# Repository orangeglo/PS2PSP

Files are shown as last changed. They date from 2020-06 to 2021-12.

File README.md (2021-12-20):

# PS2PSP

These are PCB design and arduino software files for a circuit board that converts a PS2 controller into signals a PSP2000 motherboard can understand. The circuit board is designed to have the PSP power cable routed through it, so you can boot up the PSP and the adapter with a basic toggle switch.

[Order from OSH Park](https://oshpark.com/shared_projects/nhHJAzdG)

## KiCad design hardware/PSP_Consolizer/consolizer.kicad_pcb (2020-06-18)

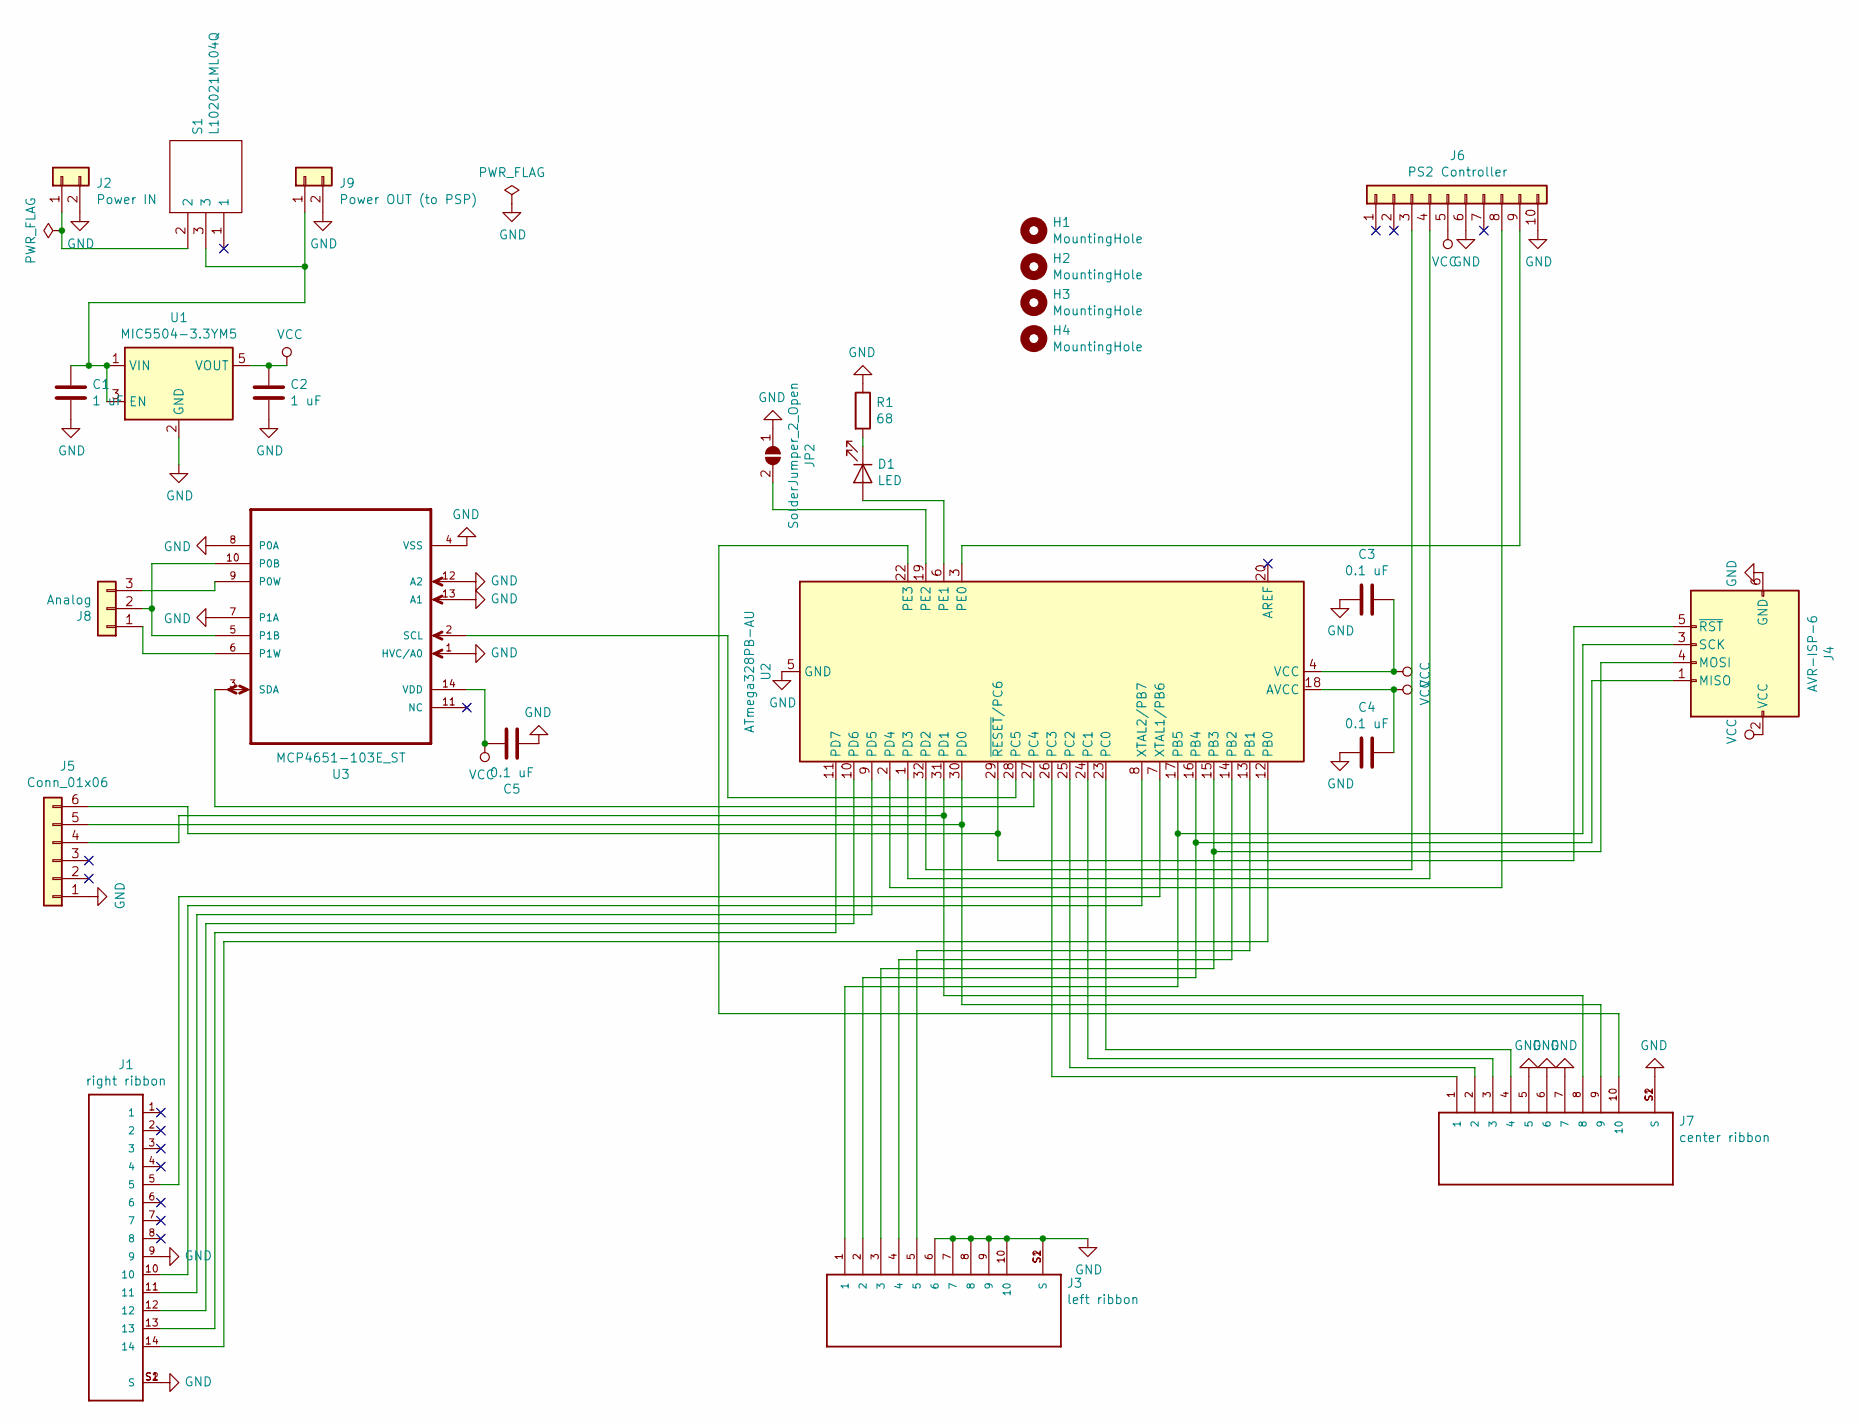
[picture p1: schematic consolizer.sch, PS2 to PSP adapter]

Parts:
C1, C2: 1 uF; C_0603_1608Metric_Pad1.05x0.95mm_HandSolder
C3, C4, C5: 0.1 uF; C_0603_1608Metric_Pad1.05x0.95mm_HandSolder
D1: LED; LED_0603_1608Metric_Pad1.05x0.95mm_HandSolder
H1, H2, H3, H4: MountingHole; MountingHole_2.2mm_M2
J1: right ribbon; TE_1-1734592-4
J2: Power IN; PinHeader_1x02_P2.54mm_Vertical
J3: left ribbon; TE_1-1734592-0
J4: AVR-ISP-6; PinHeader_2x03_P2.54mm_Vertical
J5: Conn_01x06; PinHeader_1x06_P2.54mm_Horizontal
J6: PS2 Controller; ps2_connector
J7: center ribbon; TE_1-1734592-0
J8: Analog; PinHeader_1x03_P2.54mm_Vertical
J9: Power OUT (to PSP); PinHeader_1x02_P2.54mm_Horizontal
JP2: SolderJumper_2_Open; SolderJumper-2_P1.3mm_Open_RoundedPad1.0x1.5mm
R1: 68; R_0603_1608Metric_Pad1.05x0.95mm_HandSolder
S1: L102021ML04Q; L102011ML04Q; Manufacturer_Part_Number L102021ML04Q; Mouser Part Number 611-L102021ML04Q
U1: MIC5504-3.3YM5; SOT-23-5
U2: ATmega328PB-AU; TQFP-32_7x7mm_P0.8mm
U3: MCP4651-103E_ST; SOP65P640X120-14N

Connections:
GND: C1.2, C2.2, C3.1, C4.1, C5.2, J1.9, J1.S1 (S), J1.S2 (S), J2.2, J3.6, J3.7, J3.8, J3.9, J3.10, J3.S1 (S), J3.S2 (S), J4.6 (GND), J5.1, J6.6, J6.10, J7.5, J7.6, J7.7, J7.S1 (S), J7.S2 (S), J9.2, JP2.1 (A), R1.1, U1.2 (GND), U2.5 (GND), U2.21 (GND), U3.1 (HVC/A0), U3.4 (VSS), U3.7 (P1A), U3.8 (P0A), U3.12 (A2), U3.13 (A1)
unnamed: C1.1, J9.1, S1.3, U1.1 (VIN), U1.3 (EN)
unnamed: D1.1 (K), R1.2
unnamed: D1.2 (A), U2.6 (PE1)
unnamed: J1.5, U2.7 (XTAL1/PB6)
unnamed: J1.10, U2.8 (XTAL2/PB7)
unnamed: J1.11, U2.9 (PD5)
unnamed: J1.12, U2.10 (PD6)
unnamed: J1.13, U2.11 (PD7)
unnamed: J1.14, U2.12 (PB0)
unnamed: J2.1, S1.2
unnamed: J3.1, J4.3 (SCK), U2.17 (PB5)
unnamed: J3.2, J4.1 (MISO), U2.16 (PB4)
unnamed: J3.3, J4.4 (MOSI), U2.15 (PB3)
unnamed: J3.4, U2.14 (PB2)
unnamed: J3.5, U2.13 (PB1)
unnamed: J4.5 (~RST), J5.6, U2.29 (~RESET~/PC6)
unnamed: J5.4, J7.8, U2.31 (PD1)
unnamed: J5.5, J7.9, U2.30 (PD0)
unnamed: J6.3, U2.32 (PD2)
unnamed: J6.4, U2.1 (PD3)
unnamed: J6.8, U2.2 (PD4)
unnamed: J6.9, U2.3 (PE0)
unnamed: J7.1, U2.26 (PC3)
unnamed: J7.2, U2.25 (PC2)
unnamed: J7.3, U2.24 (PC1)
unnamed: J7.4, U2.23 (PC0)
unnamed: J7.10, U2.22 (PE3)
unnamed: J8.1, U3.6 (P1W)
unnamed: J8.2, U3.5 (P1B), U3.10 (P0B)
unnamed: J8.3, U3.9 (P0W)
unnamed: JP2.2 (B), U2.19 (PE2)
unnamed: U2.27 (PC4), U3.3 (SDA)
unnamed: U2.28 (PC5), U3.2 (SCL)
VCC: C2.1, C3.2, C4.2, C5.1, J4.2 (VCC), J6.5, U1.5 (VOUT), U2.4 (VCC), U2.18 (AVCC), U3.14 (VDD)

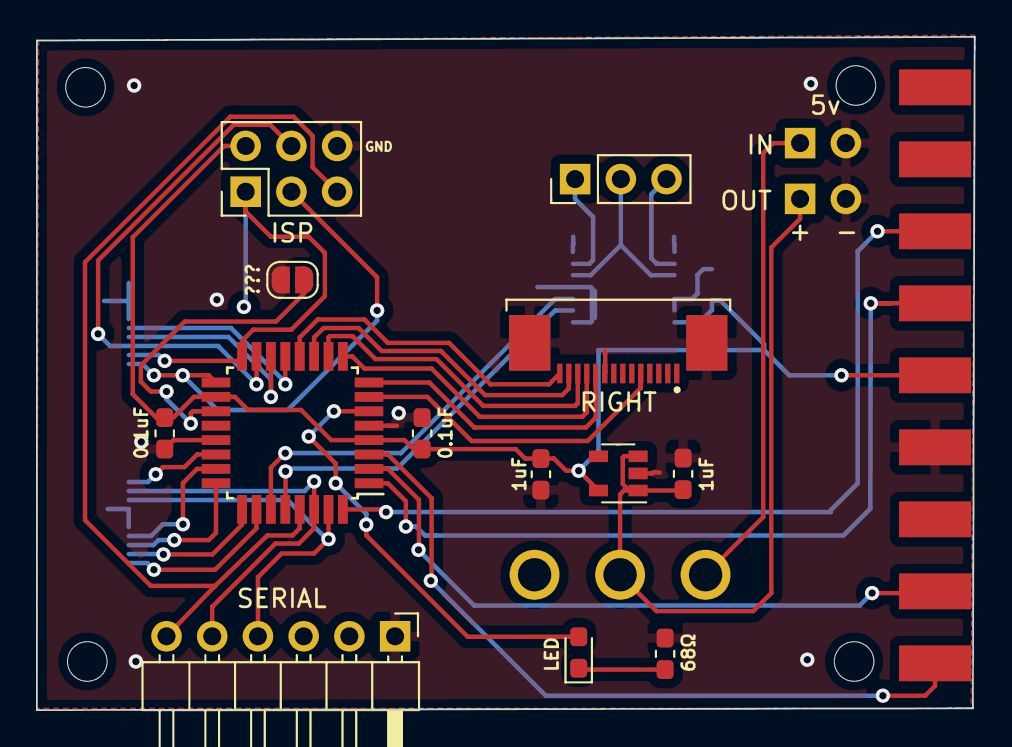
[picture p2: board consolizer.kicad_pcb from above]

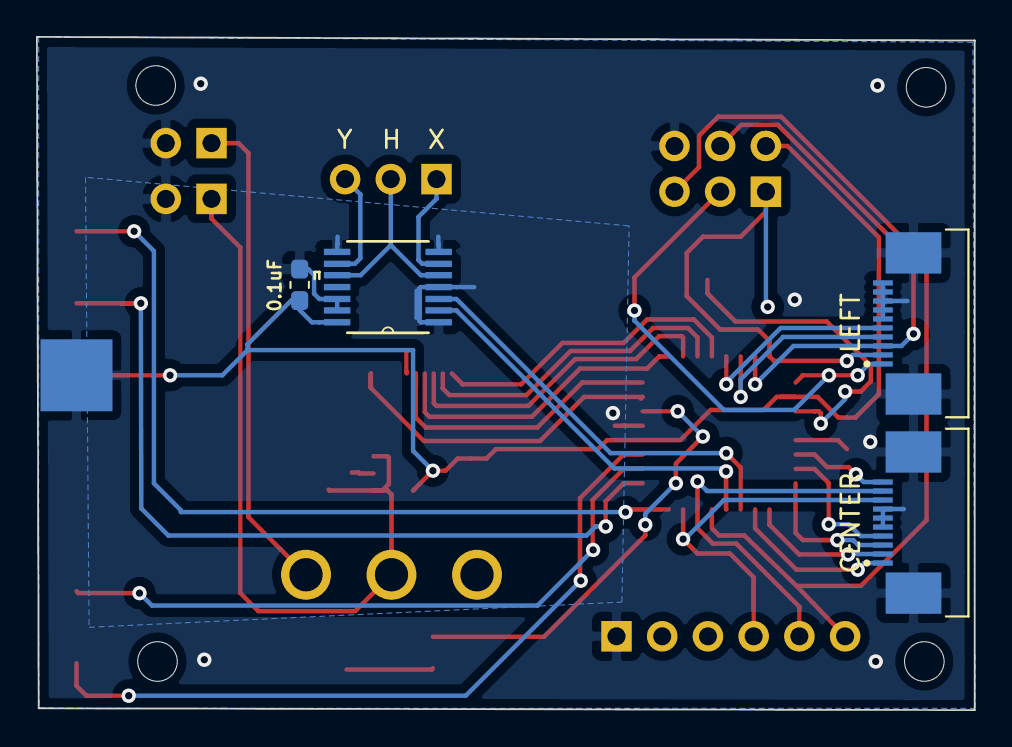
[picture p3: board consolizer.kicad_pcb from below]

Board: 2 copper layers, 52.1 x 37.4 mm, 25 parts (4 on the bottom side), 35 nets.

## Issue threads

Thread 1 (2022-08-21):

PSP 3000 compatibility

DobaMuffin, 2022-08-21:
I am wondering if this would also work with psp 3000 motherboards?

epbarger, 2022-08-21:
Unfortunately it would not as is - the ribbon cable connections are different between the two models. It would be possible to modify the design to support the 2000 though.

DobaMuffin, 2022-09-20:
I am currently looking at the necessary steps for 3000 conversion of the pcb. So far it seems almost everything maps out the same, and the board is more or less ready to accept the 3000.

epbarger, 2022-09-20:
That's great! I was under the impression the 3000 has different size flat flex cables in a few spots, but I may have been misremembering.

DobaMuffin, 2022-09-20:
It looks like the flat flex cables for the home ribbon are the same, whereas the left ribbon cable is smaller, and the right cable has a slightly different pinout towards the middle. Should be fairly simple to modify the board to support psp 3000. I'll do a bit more investigation, then modify the board design and order them to test if it works. If all is good in the end, then I'll create a merge request for it.

epbarger, 2022-09-20:
Nice, excellent work. The 3000 also uses a FFC for the joystick connection, so you could take advantage of that as well if you wanted.

DobaMuffin, 2022-09-20:
Twas my plan. I see the 3 pins for the joystick connection in the original design, and I know they get soldered on the psp 2000, but it will be easy to extend them on the board to a 4 pin ffc connector so that the psp 3000 would be a truly solderless install. I just need to check if the analog stick operates at 2.5v like what I've been reading since I don't want to damage the psp in any way by feeding it a higher voltage on those x and y signals.

epbarger, 2022-09-20:
You don't need to feed any power into the analog stick FFC, it provides the power and ground that you're using through the two digipots that output X and Y, so it's effectively isolated from the rest of the custom PCB

DobaMuffin, 2022-09-20:
What's the max voltage being sent back from the digipot? I've read that the psp pulses a 2.5v signal to the onboard analog stick, which would mean the max voltage being read from the potentiometers is 2.5v, but I see the digipot is being fed 3.3v in the design, hence my concern for potential damage.

epbarger, 2022-09-20:
2.5v sounds correct to me, but I'm not positive. I remember some parts of the PSP run as low as 1.8v logic.

The way the circuit is wired, it's not possible for the PSP to get above 2.5v on X or Y unless the digipot chip malfunctioned. The digipot only acts as a voltage divider, so with the inputs of 2.5v and GND from the joystick pins, the output X and Y can only ever be between those two values. If it was the other way around, with the digipot supply at 2.5, and the psp at 3.3, that would have the potential to damage the digipot.

DobaMuffin, 2022-09-20:
Ah, I see now. Seems I had been misreading the schematic this entire time.

DobaMuffin, 2022-09-20:
It seems as though the middle bar flex cable from a psp 3000 works in the psp 2000, so that looks to be a direct connection with no changes, the right button ribbon is the same size with the grounds for the power board lights being separate on the psp 3000 vs combined on the psp 2000, and the left side seems to be the same pitch, just with 3 pins less on the connector.

DobaMuffin, 2022-09-29:
Board design has been modified. I just need to wait a few weeks to make sure it looks good before I order them to test.

Bma36, 2023-04-04:
Hi, tutorial?

amilton33, 2023-05-25:
hello

Closed 2023-05-25.

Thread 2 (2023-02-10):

error compiling

davidxgames, 2023-02-10:
Thanks for sharing, I have some doubts, I am compiling with arduino ide, but it gives me an error for PS2X_lib.h, my question is where can I get that library?

epbarger, 2023-02-10:
Hi, you need to install https://github.com/madsci1016/Arduino-PS2X into your arduino library

davidxgames, 2023-02-10:
Thanks for answering, I already installed the library, but I have this error: "DDRE was not declared in this scope". Should I compile with some version of arduino ide?

epbarger, 2023-02-10:
Yeah you need to make sure you're compiling for the 328P**B**, which has Port E. I recommend installing the [MiniCore](https://github.com/MCUdude/MiniCore) hardware package, it makes working with the bare chips much easier :)

epbarger, 2023-02-10:
You'd select 328PB, internal 8mhz clock

davidxgames, 2023-02-10:
so the mega328pu doesn't work in this project?

thanks for the help installing the MiniCore

epbarger, 2023-02-10:
PU is a manufacturing code btw, the only real variants I'm aware of are 328, 328P, and 328PB

davidxgames, 2023-02-10:
Yes, I'm using an arduino nano that has ATMEGA328p, I'll look for a separate MEGA328pb.

epbarger, 2023-02-10:
It looks like the trigger for the HOME button is the only thing the code uses Port E for. If you're using an arduino nano you can probably move that to a different port yourself

davidxgames, 2023-02-10:
> Parece que el activador del botón INICIO es lo único para lo que el código usa el Puerto E. Si está utilizando un arduino nano, probablemente pueda cambiar el código para moverlo a un puerto diferente usted mismo

I'll try it, I'll post the results later.

davidxgames, 2023-02-10:
From what I checked, if I want to use the 328pu I will have to modify all the pins in the code, since the 328pb and the 329pu have a different pinout.

davidxgames, 2023-02-10:
I think there is an error in the following:

#define PS2_DAT 23
#define PS2_CMD 4
#define PS2_SEL 3
#define PS2_CLK 2

pin 23 in the schematic goes to pin 4 of the center ribbon
pin 4 goes to vcc

Sorry if I'm wrong, I'm a noob.

epbarger, 2023-02-10:
Ah looks like I used Port E for the PS2_DAT, you'll need to change that too.

328PB https://europe1.discourse-cdn.com/arduino/optimized/4X/b/3/6/b362b3222b11ae632320538b09123c47c4fc6d32_2_428x500.jpeg

328P https://external-content.duckduckgo.com/iu/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

davidxgames, 2023-03-05:
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

In the end I used an esp32 and it worked fine, you have to modify the PS2X library to make it work on esp32.

epbarger, 2023-03-05:
That's great, I'm glad you got it working!

Bma36, 2023-05-16:
can you share a tutorial on how you used esp32?

Closed 2023-03-05.

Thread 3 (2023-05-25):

Basic component guide

amilton33, 2023-05-25:
Hello, I want to contribute to the project to add a blueretro directly to the ps2 controller port, would you have a guide with the name of the components used?

luizoti, 2023-05-26:
Good idea, I suppose it is possible to integrate a small esp32 inside the psp, allowing mixed use when connecting to the tv and connecting the controller.

Cyrus331, 2023-05-30:
I also thought of this idea, this project plus blueretro I think it can be realized，I hope orangeglo can make it happen ;)

Cyrus331, 2023-05-31:
Yes, I have also paid attention to the PSP-Consolizer project, but that project is more complicated, and the combination of blueretro and PS2PSP will be much simpler.

amilton33, 2023-05-31:
But you don't need to do this project to use the blueretro later, just use an Esp-32 with the bluepad32 library and you will have the same result with the bluetooth option, or you can do this project and instead of putting a ps2 pad on the pcb, connect it directly to an esp-32 with a ps2 blueretro already installed on it.

luizoti, 2023-06-01:
I think blueretro would bring more flexibility of controls, because it would be possible to connect any compatible with it.

Bma36, 2023-06-01:
As I said before, to add the blueretro to this project just compile the esp-32 and solder the wires according to the PS2 blueretro schematic to the points on the pcb where the control connector goes

Bma36, 2023-06-01:
As I said before, to add the blueretro to this project just compile the esp-32 and solder the wires according to the PS2 blueretro schematic to the points on the pcb where the control connector goes

Cyrus331, 2023-06-29:
Have any friends realized this project? I am trying to make a PCB now, but I found that there seem to be two versions. The difference lies in the anlog, one with connectro and one without. Is the final version with connectro? Does this need to be linked? I can’t see it from the picture here[https://epbarger.github.io/assets/psp_consolized.jpg](url)

epbarger, 2023-06-29:
The PS2 controller port connector is harvested from one of these cheap usb adapters - https://www.aliexpress.us/item/3256803457150606.html

Bma36, 2023-06-29:
Remembering that this code is for the atmega 328PB, but changing the code you can compile it on the atmega328P, I will add an esp-32 with blueretro.

davidxgames, 2023-06-29:
> Creo que blueretro traería más flexibilidad de controles, porque sería posible conectar cualquiera compatible con él.

In theory blueretro and Bluepad have the same control compatibility, something that can be added with bluepad is rumble every time you shoot in a game, and use the right stick to control the X OR square and triangle buttons, in FPS.

davidxgames, 2023-06-29:
> Creo que blueretro traería más flexibilidad de controles, porque sería posible conectar cualquiera compatible con él.

In theory blueretro and Bluepad have the same control compatibility, something that can be added with bluepad is rumble every time you shoot in a game, and use the right stick to control the X OR square and triangle buttons, in FPS.

Bma36, 2023-06-30:
> There's already one with bluetooth functionality, now the creator is adapting it for the psp 3000
> https://github.com/ste2425/PSP-Consolizer

The project with this pcb is great, include blueretro and still have the option to use dualshock with cable, for those who want an internal consolizer with esp-32, above there is the link of the developer Scoop that already made the project with an arduino nano 33

Cyrus331, 2023-06-30:
> 请记住，此代码适用于 atmega 328PB，但更改代码后您可以在 atmega328P 上编译它，我将添加带有 blueretro 的 esp-32。

looking forward to your work

amilton33, 2023-07-07:
I adapted the code to use an atmega 328P in an arduino nano, I am waiting for the apartment cables and fpcs ordered at aliexpress to arrive, as soon as I do the tests I will add blueretro so that it can have physical connection with ps2 control and wireless.

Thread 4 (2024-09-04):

On and off

edgaresn, 2024-09-04:
Hi I’m sorry for bother you with this I’m new to this have little experience but I’m trying lol

I got the board ready code , components everything and it works fine what’s happens now it’s when I turn it off and turn it on right away I don’t get no signal  display but the board it’s on and the psp board looks like it’s completely off still this issue only happens on my end or there is something else that I need to do

 To have it on again and have display signal on tv again have to wait at least 40+ min to get the psp board give me display again any idea what I’m doing wrong ?

epbarger, 2024-09-05:
Hey, I'm happy to see you have the project mostly working! Hopefully you can figure out this issue.

- What cables are you using to display the PSP on the TV?
- Could you post a detailed photo of your circuit board?
- What power adapter are you using? The PSP and adapter board should both be powered at the same time through the power switch.

edgaresn, 2024-09-06:
Hey thank you so much for your help

im using a generic cable from ally express
To have display on tv

Power source : the og charger for the psp and I’m powering  both at the same time.
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

epbarger, 2024-09-06:
Hmm hard to say with certainty what's going on. I would try to redo your soldering for all of the power connection wires, those solder joints don't look the best. Particularly the ones on the PSP.

 Are you using the same power switch as I did? Can't see it in your photo. I would guess the issue is one of the following...

- Faulty power supply (seems unlikely if you're using the sony one)
- Bad solder connections between power jack and board, or board and psp

Hope you get it sorted out! Check the soldering of the wire! If you have flux paste that will help a lot. The PSP is a little tricky to solder to since it has many copper layers.

edgaresn, 2024-09-07:
Thanks for your tips sorry for the late reply too

yes I’m using same switch as you , I going to use a different power supply too

I will assemble another board with a different psp board too. to conduct a new test I will let you know how ends

edgaresn, 2024-09-08:
I assembled another board today everything new into it , new psp board (2001) new power supply, new ribbon cable

But it seems to be a problem with the board (consolized)  not the psp main board

To me looks like the ATMEGA328PB is not sending the start up signal when I turn it on everything works fine.  I have display but if I turn it off and turn it back on have no signal, psp board have power. Consolized board have power I know cause the led is on but still no display

epbarger, 2024-09-08:
Hey, have you tried the power on key combination on the PS2 controller? Hold L2 + R2, and then press select for a second or so. Maybe that's all your missing?

Sorry, I know the support on this project is not great, this was something a made a while ago and haven't revisited since. I'd recommend looking through the code for help with the key combinations if you haven't already. Hopefully it's not too hard to understand!

epbarger, 2024-09-08:
There is also a key combination to toggle video output that you may need - https://github.com/orangeglo/PS2PSP/blob/77ef450e47e3f08ba5d41448dfbbaad8b562ee82/firmware/ps2psp/ps2psp.ino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. All the secondary functions use L2 + R2 to access

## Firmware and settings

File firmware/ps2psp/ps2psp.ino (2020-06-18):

/*
 * PS2 to PSP Arduino Firmware
 * 
 * IDEAS
 * Reconsider caching button presses each loop
 */

#include <Wire.h>
#include <PS2X_lib.h>

#define JUMPER_PIN 25

// PS2 Controller //////////////////
#define PS2_DAT 23
#define PS2_CMD 4
#define PS2_SEL 3
#define PS2_CLK 2

PS2X ps2x;
byte ps2xError = 1; // starts as 1 to trigger the initial connection attempt


// PSP Button Pins //////////////////
#define PORT_B 0
#define PORT_C 1
#define PORT_D 2
#define PORT_E 3

typedef struct {
  const byte port;
  const byte num;
  bool pressed;
} pinDef;

pinDef upPin = { PORT_B, 3 };
pinDef downPin = { PORT_B, 1 };
pinDef leftPin = { PORT_B, 2 };
pinDef rightPin = { PORT_B, 4 };
pinDef leftShoulderPin = { PORT_B, 5 };

pinDef crossPin = { PORT_B, 7 };
pinDef squarePin = { PORT_B, 0 };
pinDef circlePin = { PORT_D, 5 };
pinDef trianglePin = { PORT_D, 6};
pinDef rightShoulderPin = { PORT_D, 7 };
pinDef powerPin = { PORT_B, 6 };

pinDef homePin = { PORT_E, 3 };
// pinDef volumeDownPin = { PORT_D, 0 }; // serial
// pinDef volumeUpPin = { PORT_D, 1 }; // serial
pinDef videoPin = { PORT_C, 0 };
pinDef eqPin = { PORT_C, 1 };
pinDef selectPin = { PORT_C, 2 };
pinDef startPin = { PORT_C, 3 };


// Button Mappings ///////////////////
#define SECONDARY_MAPPING_COMBO_HOLD_MILLIS 250

typedef struct {
  pinDef* pin;
  unsigned int buttonA;
  unsigned int buttonB;
} pinButtonMapping;

typedef struct {
  unsigned int buttonA;
  unsigned int buttonB;
  unsigned long pressedMillis;
} buttonCombo;

pinButtonMapping primaryMappings[] = {
  { &upPin, PSB_PAD_UP },
  { &downPin, PSB_PAD_DOWN },
  { &leftPin, PSB_PAD_LEFT },
  { &rightPin, PSB_PAD_RIGHT },
  { &leftShoulderPin, PSB_L1, PSB_L2 },

  { &crossPin, PSB_CROSS },
  { &squarePin, PSB_SQUARE },
  { &circlePin, PSB_CIRCLE },
  { &trianglePin, PSB_TRIANGLE },
  { &rightShoulderPin, PSB_R1, PSB_R2 },

  { &startPin, PSB_START },
  { &selectPin, PSB_SELECT }
};
const byte primaryMappingsSize = sizeof(primaryMappings) / sizeof(pinButtonMapping);

pinButtonMapping secondaryMappings[] = {
  { &homePin, PSB_START },
  { &powerPin, PSB_SELECT },
  { &videoPin, PSB_SQUARE },
  { &eqPin, PSB_CIRCLE },
  //  { &volumeUpPin, PSB_PAD_UP },
  //  { &volumeDownPin, PSB_PAD_DOWN },
};
const byte secondaryMappingsSize = sizeof(secondaryMappings) / sizeof(pinButtonMapping);

buttonCombo secondaryMappingCombo = { PSB_L2, PSB_R2 };
pinButtonMapping *currentMapping = primaryMappings;
byte currentMappingSize = primaryMappingsSize;


// Analog Sticks ////////////////////
#define LEFT_STICK_DEADZONE 30
#define LEFT_ANALOG_MODE_COUNT 2
#define LEFT_ANALOG_MODE_STICK 0
#define LEFT_ANALOG_MODE_PSX 1

#define THRESHOLD_STICK_DEADZONE 50
#define RIGHT_ANALOG_MODE_COUNT 2
#define RIGHT_ANALOG_MODE_DISABLED 0
#define RIGHT_ANALOG_MODE_THRESHOLD 1

byte leftAnalogMode = 0;
byte rightAnalogMode = 0;
byte thresholdMagnitude;
double thresholdAngle;


// LED /////////////////////////////
#define LED_PIN 24

byte ledTotalPulses = 0;
byte ledCurrentPulse = 0;
byte ledPulseLengthMillis = 50;
unsigned long ledLastMillis = 0;


// Setup & Loop //////////////////////////

void setup() {
  Serial.begin(57600);

  Wire.begin();
  centerPot();
  pinMode(JUMPER_PIN, INPUT_PULLUP);
  pinMode(LED_PIN, OUTPUT);
  digitalWrite(LED_PIN, HIGH);

  delay(500); // wait for psp to accept power signal
  if (digitalRead(JUMPER_PIN)) { // if jumper open
    powerUp();  
    delay(14000); // wait for date/time screen
    digitalWrite(LED_PIN, LOW);
    startVideoOut();
  }
  
  while (ps2xError) { // wait for controller and connect
    ps2xError = ps2x.config_gamepad(PS2_CLK, PS2_CMD, PS2_SEL, PS2_DAT, false, false);
  }
  digitalWrite(LED_PIN, HIGH);
}

void loop() {
  delay(2);
  ps2x.read_gamepad();
  updateLedFlash();

  updateCurrentMapping();
  resetPinPressed();

  updateButtons(currentMapping, currentMappingSize);
  updateLeftAnalog();
  updateRightAnalog();

  releaseUnusedPins();
}

// Functions ////////////////////////////

void updateButtons(pinButtonMapping mapping[], byte mappingSize){
  for (byte i = 0; i < mappingSize; i++){
    if (ps2x.Button(mapping[i].buttonA) || (!psxModeActive() && mapping[i].buttonB && ps2x.Button(mapping[i].buttonB))) {
      pressPin(mapping[i].pin);
    }

    if (psxModeActive()) { handleL2R2PSX(); }
  }
}

void handleL2R2PSX() {
  if (ps2x.Button(PSB_L2) && ps2x.Button(PSB_R2)) {
    setPot(127, 64); // up
  } else if (ps2x.Button(PSB_L2)) {
    setPot(64, 127); // left
  } else if (ps2x.Button(PSB_R2)) {
    setPot(191, 127); // right
  } else {
    centerPot();
  }
}

void updateCurrentMapping() {
  if (ps2x.Button(secondaryMappingCombo.buttonA) && ps2x.Button(secondaryMappingCombo.buttonB)){
    if (!secondaryMappingCombo.pressedMillis) { secondaryMappingCombo.pressedMillis = millis(); }
  } else {
    secondaryMappingCombo.pressedMillis = 0;
  }

  if (secondaryMappingCombo.pressedMillis && (millis() - secondaryMappingCombo.pressedMillis > SECONDARY_MAPPING_COMBO_HOLD_MILLIS)){
    currentMapping = secondaryMappings;
    currentMappingSize = secondaryMappingsSize;
  } else {
    currentMapping = primaryMappings;
    currentMappingSize = primaryMappingsSize;
  }
}

void pressPin(pinDef* pin){
  pin->pressed = true;

  switch(pin->port){
    case PORT_B:
      DDRB = DDRB | (1 << pin->num);
      PORTB = PORTB & ~(1 << pin->num);
      break;
    case PORT_C:
      DDRC = DDRC | (1 << pin->num);
      PORTC = PORTC & ~(1 << pin->num);
      break;
    case PORT_D:
      DDRD = DDRD | (1 << pin->num);
      PORTD = PORTD & ~(1 << pin->num);
      break;
    case PORT_E:
      DDRE = DDRE | (1 << pin->num);
      PORTE = PORTE & ~(1 << pin->num);
      break;
  }
}

void releasePin(pinDef* pin){
  switch(pin->port){
    case PORT_B:
      DDRB = DDRB & ~(1 << pin->num);
      break;
    case PORT_C:
      DDRC = DDRC & ~(1 << pin->num);
      break;
    case PORT_D:
      DDRD = DDRD & ~(1 << pin->num);
      break;
    case PORT_E:
      DDRE = DDRE & ~(1 << pin->num);
      break;
  }
}

void resetPinPressed() {
  for(byte i = 0; i < currentMappingSize; i++){
    currentMapping[i].pin->pressed = false;
  }
}

void releaseUnusedPins(){
  for(byte i = 0; i < currentMappingSize; i++){
    if (!(currentMapping[i].pin->pressed)){
      releasePin(currentMapping[i].pin);
    }
  }
}

int magnitude(int x, int y) {
  return sqrt((pow(x, 2)+pow(y, 2)));
}

byte currentTick = 0;
byte tickLength = 16; // ms ~60fps
unsigned long tickTime = 0;
void updateLeftAnalog(){
  if (ps2x.ButtonReleased(PSB_L3)){
    leftAnalogMode = (leftAnalogMode + 1) % LEFT_ANALOG_MODE_COUNT;
    centerPot();
    startLedFlash(2, 100);
  }

  switch(leftAnalogMode){
    case LEFT_ANALOG_MODE_STICK:
      if (magnitude(ps2x.Analog(PSS_LX) - 127, ps2x.Analog(PSS_LY) - 127) > LEFT_STICK_DEADZONE){
        setPot(127 + ((ps2x.Analog(PSS_LX) - 127) / 1.5), 127 + ((ps2x.Analog(PSS_LY) - 127) / 1.5));
      } else {
        centerPot();
      }
      break;
    case LEFT_ANALOG_MODE_PSX:
      thresholdStick(PSS_LX, PSS_LY, &downPin, &upPin, &leftPin, &rightPin);
      break;
  }
}

void updateRightAnalog(){
  if (ps2x.ButtonReleased(PSB_R3)){
    rightAnalogMode = (rightAnalogMode + 1) % RIGHT_ANALOG_MODE_COUNT;
    startLedFlash(2, 100);
  }
  
  switch(rightAnalogMode){
    case RIGHT_ANALOG_MODE_THRESHOLD:
      thresholdStick(PSS_RX, PSS_RY, &crossPin, &trianglePin, &squarePin, &circlePin);
      break;
  }
}

void thresholdStick(unsigned int xAxis, unsigned int yAxis, pinDef* up, pinDef* down, pinDef* left, pinDef* right){
  thresholdMagnitude = magnitude(ps2x.Analog(xAxis) - 127, ps2x.Analog(yAxis) - 127);
  if (thresholdMagnitude > THRESHOLD_STICK_DEADZONE){
    thresholdAngle = atan2(ps2x.Analog(yAxis) - 127, ps2x.Analog(xAxis) - 127);
    if (thresholdAngle < 0) { thresholdAngle += 6.2832; }

    if (thresholdAngle >= 0.3972 && thresholdAngle <= 1.1781){ pressPin(up); pressPin(right); } // up right
    else if (thresholdAngle >= 1.1781 && thresholdAngle <= 1.9635){ pressPin(up); } // up
    else if (thresholdAngle >= 1.9635 && thresholdAngle <= 2.7489){ pressPin(up); pressPin(left); } // up left
    else if (thresholdAngle >= 2.7489 && thresholdAngle <= 3.5343){ pressPin(left); } // left
    else if (thresholdAngle >= 3.5343 && thresholdAngle <= 4.3197){ pressPin(down); pressPin(left); } // down left
    else if (thresholdAngle >= 4.3197 && thresholdAngle <= 5.1051){ pressPin(down); } // down
    else if (thresholdAngle >= 5.1051 && thresholdAngle <= 5.8905){ pressPin(down); pressPin(right); } // down right
    else if (thresholdAngle >= 5.8905 || thresholdAngle <= 0.3972){ pressPin(right); } // right
  }
}

void setPot(byte x, byte y){
  Wire.beginTransmission(0);
  Wire.write(B10000000);
  Wire.write(x);
  Wire.write(0);
  Wire.endTransmission();

  Wire.beginTransmission(0);
  Wire.write(B10010000);
  Wire.write(y);
  Wire.write(0);
  Wire.endTransmission();
}

void centerPot(){
  setPot(127, 127);
}

bool psxModeActive(){
  return (leftAnalogMode == LEFT_ANALOG_MODE_PSX);
}

void powerUp(){
  pressPin(&powerPin);
  delay(500);
  releasePin(&powerPin);
}

void startVideoOut(){
  pressPin(&videoPin);
  delay(5000);
  releasePin(&videoPin);
}

void startLedFlash(byte pulses, byte pulseLength) {
  ledCurrentPulse = 0;
  ledTotalPulses = pulses * 2;
  ledPulseLengthMillis = pulseLength;
}

void updateLedFlash() {
  if (ledCurrentPulse >= ledTotalPulses) { return; }

  if (millis() - ledLastMillis >= ledPulseLengthMillis){
    ledLastMillis = millis();
    ledCurrentPulse++;
    if (ledCurrentPulse == ledTotalPulses) {
      digitalWrite(LED_PIN, HIGH);
    } else {
      digitalWrite(LED_PIN, !digitalRead(LED_PIN));
    }
  }
}

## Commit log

2020-01-17 Add secondary mode switching
2020-01-20 Add basic PWM mode for right analog
2020-06-18 Update firmware and add kicad files
    [consolizer.kicad_pcb, consolizer.sch, ps2_consolizer.dsn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]
